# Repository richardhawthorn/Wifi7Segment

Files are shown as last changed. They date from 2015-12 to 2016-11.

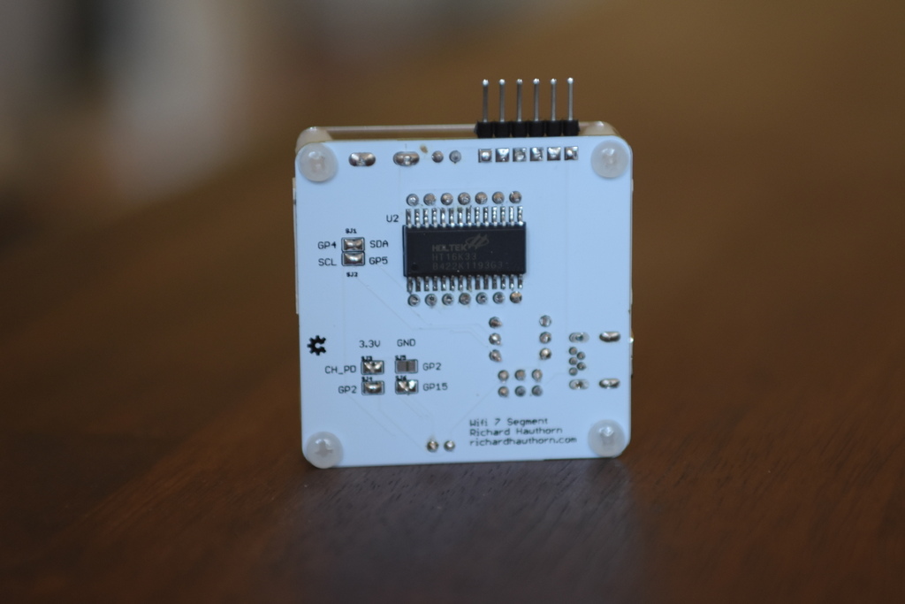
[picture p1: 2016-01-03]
images/DSC_4973.JPG

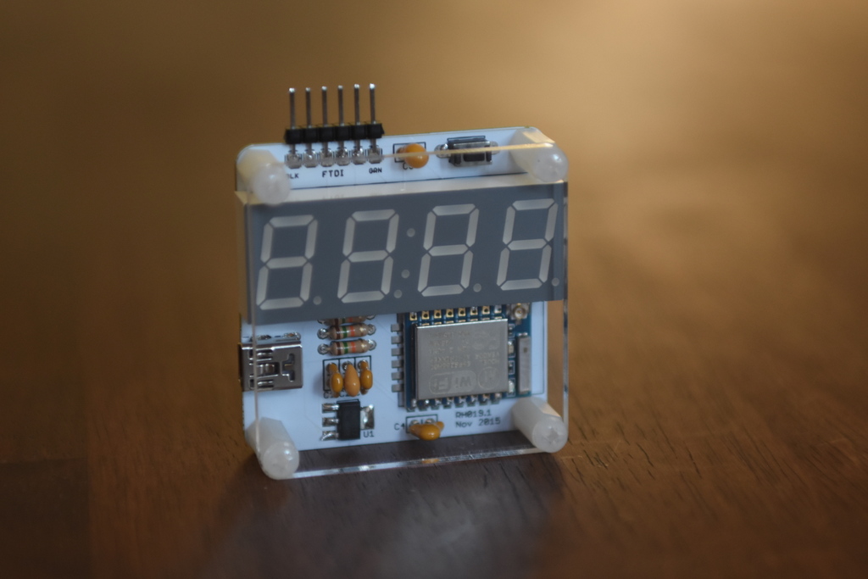
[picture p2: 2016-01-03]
images/DSC_4970.JPG

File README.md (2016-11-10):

### Features

- 0.56" 7 segment display, 4 character
- ESP8266 ESP7/12/12E Processor
- Wifi connected
- HT16K33 i2c LED driver
- 3.3V operation
- Mini USB power connector
- FTDI programming port
- Through hole technology

### License

This work is licensed under a Creative Commons Attribution-ShareAlike 4.0 International License.

<br />
Designed by <a xmlns:cc="http://creativecommons.org/ns#" href="http://www.richardhawthorn.com" property="cc:attributionName" rel="cc:attributionURL" target="_blank">Richard Hawthorn</a><br />
<a rel="license" href="http://creativecommons.org/licenses/by-sa/4.0/" target="_blank">View License</a>

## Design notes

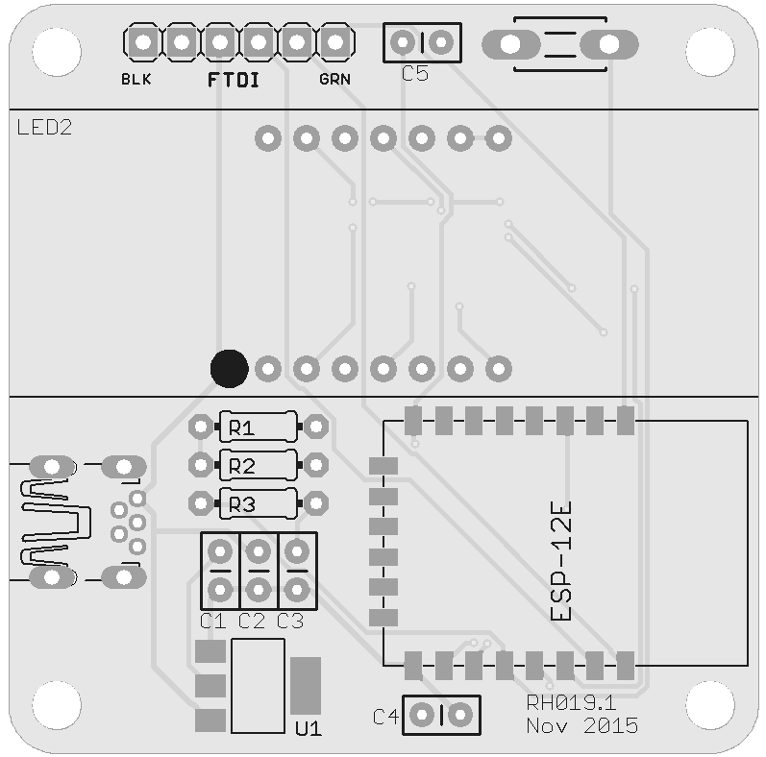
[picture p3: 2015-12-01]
images/pcb_front.png

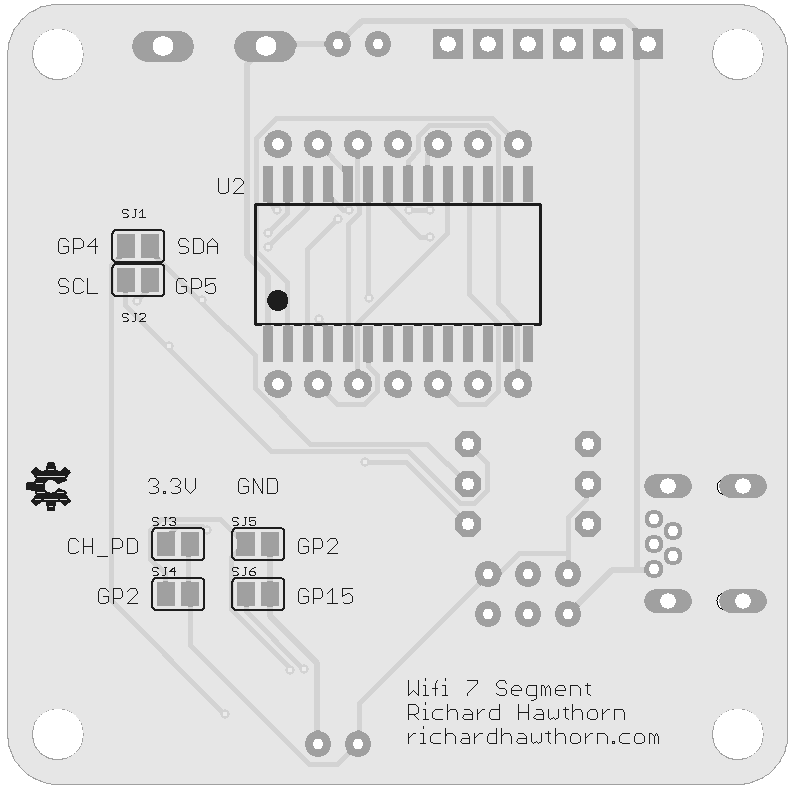
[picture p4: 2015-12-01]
images/pcb_back.png

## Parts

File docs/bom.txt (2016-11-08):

Part Value   Device                                                      
BTN1 Program DTS-3                                                                                                                
C1   0.1uf   Capacitor                                                                                                
C2   1uf     Capacitor                                                                                           
C3   10uf    Capacitor                                                                                             
C4   0.1uf   Capacitor                                                                                         
C5   0.1uf   Capacitor                                                                                            
CN4  FTDI    PINHD-1X6                                                                                                   
LED2 LED     DISP_SEGMENT_4DIGIT                                                                                             
MDL1 12E     ESP8266-ESP12E     	                              
R1   10k     Resistor                                                                     
R2   10k     Resistor                                                         
R3   10k     Resistor                                                                                                                           
U1   REG1117 SOT223 3.3V Regulator                      
U2   SOP28   HT16K33_SOP28                                                                                                
X1   USB     MINI USB-B R/A DIP 5pol

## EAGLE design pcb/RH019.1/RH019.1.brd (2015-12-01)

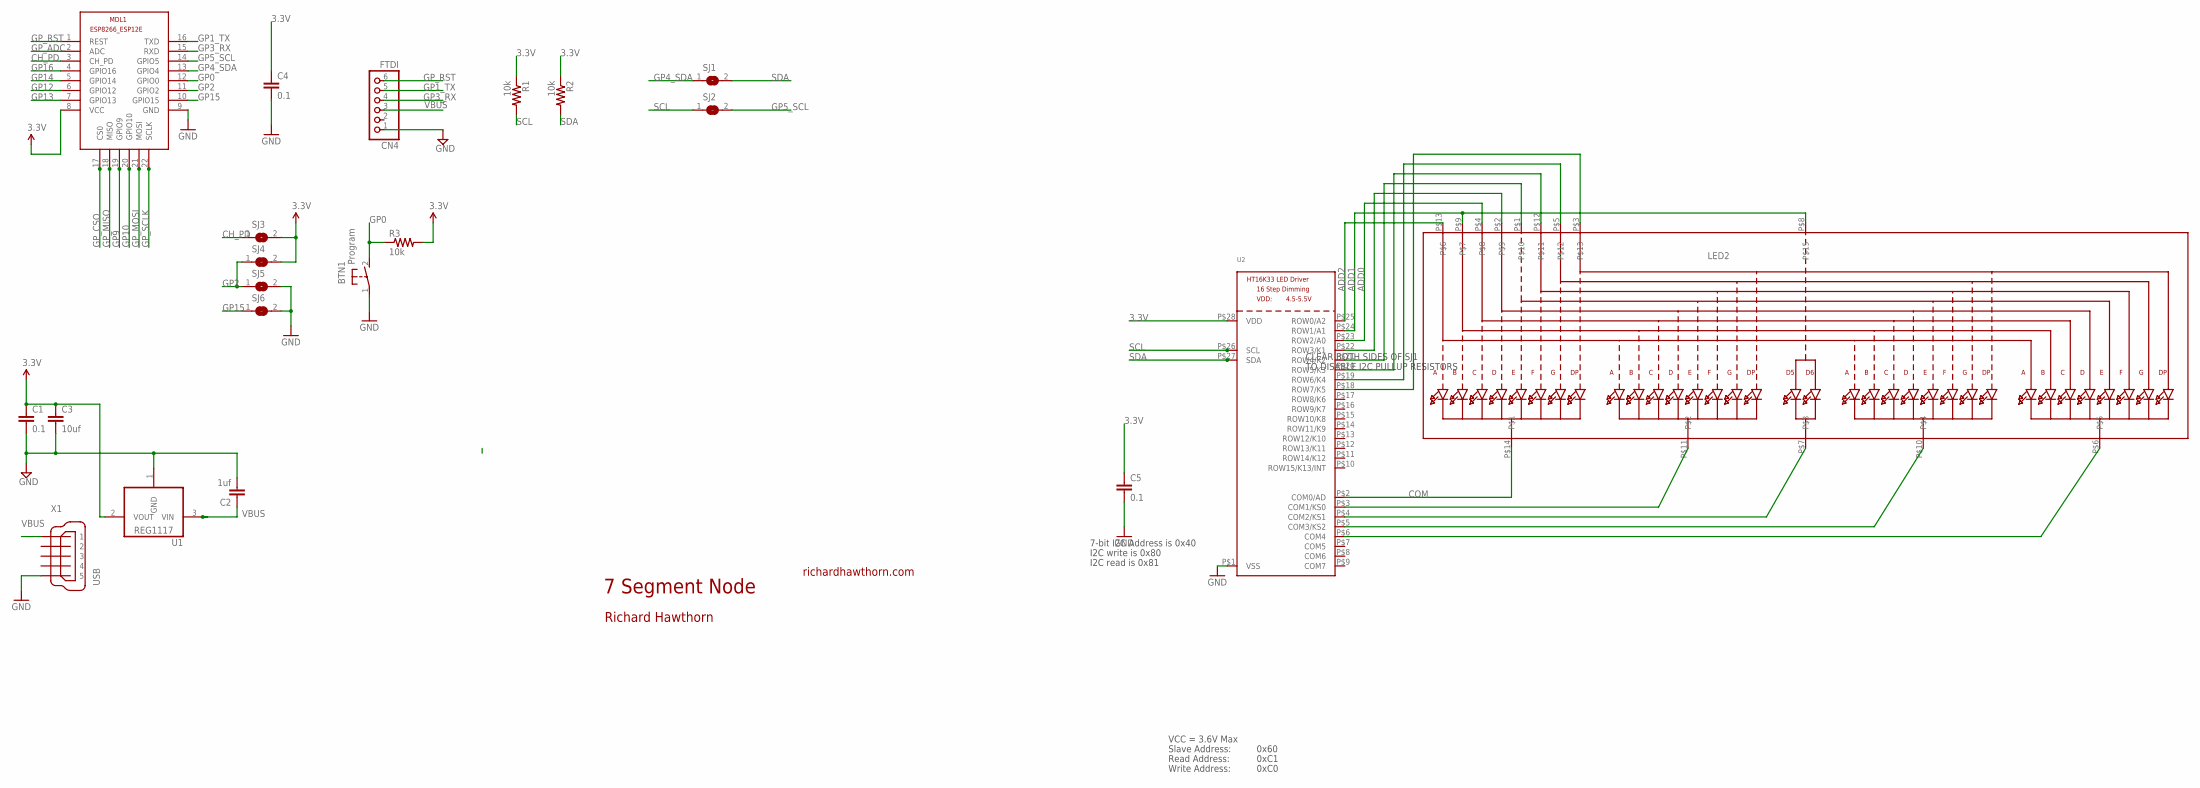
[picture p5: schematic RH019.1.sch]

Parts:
BTN1: Program; DTS-3
C1, C4, C5: 0.1; CAP-PTH-SMALL2
C2: 1uf; CAP-PTH-SMALL2
C3: 10uf; CAP-PTH-SMALL2
CN4: FTDI; 1X06
LED2: DISP_SEGMENT_4DIGIT_BL-Q56C43; SEGMENT-BL-Q56C43
MDL1: ESP8266-12EESP8266-ESP12E; ESP8266-ESP12E
R1, R2, R3: 10k; 0204/7
SJ1, SJ2, SJ3, SJ4, SJ5, SJ6: SJ
U1: REG1117; SOT223
U2: HT16K33_SOP28; SOP28_300MIL
X1: USB; 32005-601

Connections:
3.3V: C1.1, C3.1, C4.1, C5.1, MDL1.8 (VCC), R1.1, R2.1, R3.2, SJ3.2, SJ4.2, U1.2 (VOUT), U2.P$28 (VDD)
ADD0: LED2.P$4, U2.P$23 (ROW2/A0)
ADD1: LED2.P$8, LED2.P$9, U2.P$24 (ROW1/A1)
ADD2: LED2.P$13, U2.P$25 (ROW0/A2)
CH_PD: MDL1.3 (CH_PD), SJ3.1
COM: LED2.P$14, U2.P$2 (COM0/AD)
GND: BTN1.1, C1.2, C2.2, C3.2, C4.2, C5.2, CN4.1, MDL1.9 (GND), SJ5.2, SJ6.2, U1.1 (GND), U2.P$1 (VSS), X1.5
GP0: BTN1.2, MDL1.12 (GPIO0), R3.1
GP1_TX: CN4.5, MDL1.16 (TXD)
GP2: MDL1.11 (GPIO2), SJ4.1, SJ5.1
GP3_RX: CN4.4, MDL1.15 (RXD)
GP4_SDA: MDL1.13 (GPIO4), SJ1.1
GP5_SCL: MDL1.14 (GPIO5), SJ2.2
GP9: MDL1.19 (GPIO9)
GP10: MDL1.20 (GPIO10)
GP12: MDL1.6 (GPIO12)
GP13: MDL1.7 (GPIO13)
GP14: MDL1.5 (GPIO14)
GP15: MDL1.10 (GPIO15), SJ6.1
GP16: MDL1.4 (GPIO16)
GP_ADC: MDL1.2 (ADC)
GP_CSO: MDL1.17 (CS0)
GP_MISO: MDL1.18 (MISO)
GP_MOSI: MDL1.21 (MOSI)
GP_RST: CN4.6, MDL1.1 (REST)
GP_SCLK: MDL1.22 (SCLK)
unnamed: LED2.P$11, U2.P$3 (COM1/KS0)
unnamed: LED2.P$7, U2.P$4 (COM2/KS1)
unnamed: LED2.P$10, U2.P$5 (COM3/KS2)
unnamed: LED2.P$6, U2.P$6 (COM4)
unnamed: LED2.P$2, U2.P$22 (ROW3/K1)
unnamed: LED2.P$1, U2.P$21 (ROW4/K2)
unnamed: LED2.P$12, U2.P$20 (ROW5/K3)
unnamed: LED2.P$5, U2.P$19 (ROW6/K4)
unnamed: LED2.P$3, U2.P$18 (ROW7/K5)
SCL: R1.2, SJ2.1, U2.P$26 (SCL)
SDA: R2.2, SJ1.2, U2.P$27 (SDA)
VBUS: C2.1, CN4.3, U1.3 (VIN), X1.1

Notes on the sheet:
7 Segment Node
richardhawthorn.com
Richard Hawthorn
CLEAR BOTH SIDES OF SJ1
TO DISABLE I2C PULLUP RESISTORS
7-bit I2C Address is 0x40
I2C write is 0x80
I2C read is 0x81
VCC = 3.6V Max
Read Address:
Write Address:
Slave Address:
0x60
0xC1
0xC0

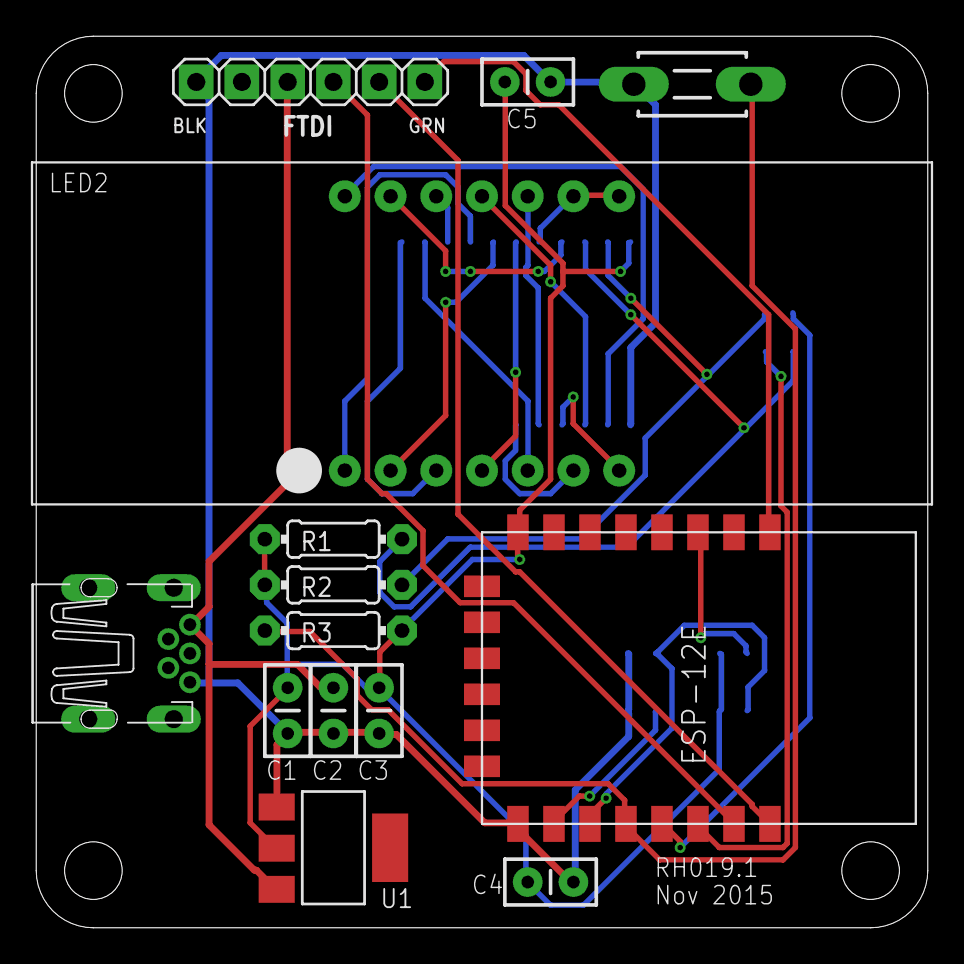
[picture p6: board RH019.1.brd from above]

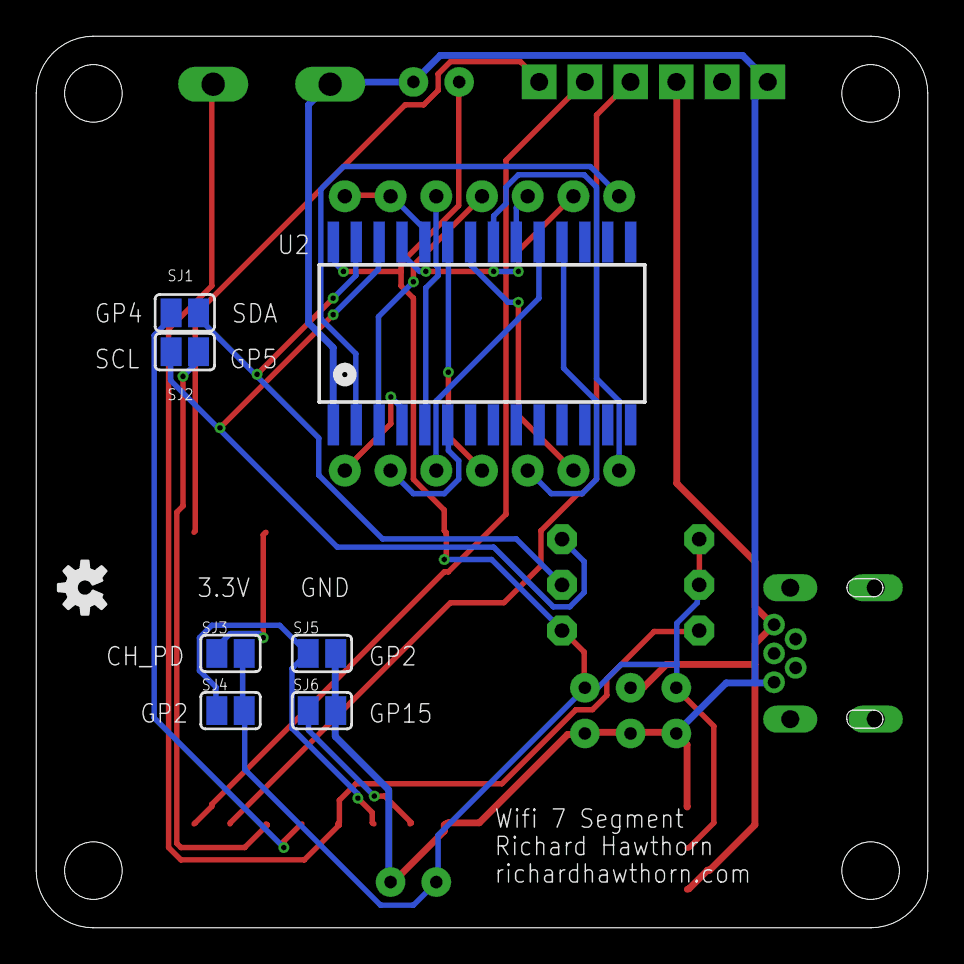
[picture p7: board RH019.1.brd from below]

Board: 2 copper layers, 49.5 x 49.5 mm, 22 parts (8 on the bottom side), 27 nets.

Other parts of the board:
U$3: OSHW-LOGO-S

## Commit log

2015-11-10 First version added
    [RH019.1.brd, RH019.1.sch]
2015-11-10 added gerbers
2015-12-01 updated pcb and gerbers
    [RH019.1.brd]
2016-11-08 added bom

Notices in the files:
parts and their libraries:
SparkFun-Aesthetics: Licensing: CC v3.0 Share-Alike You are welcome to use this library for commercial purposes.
